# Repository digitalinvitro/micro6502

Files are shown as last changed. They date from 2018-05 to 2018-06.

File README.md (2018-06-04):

# micro6502

6502 cpu based micro module (for mcu applications)

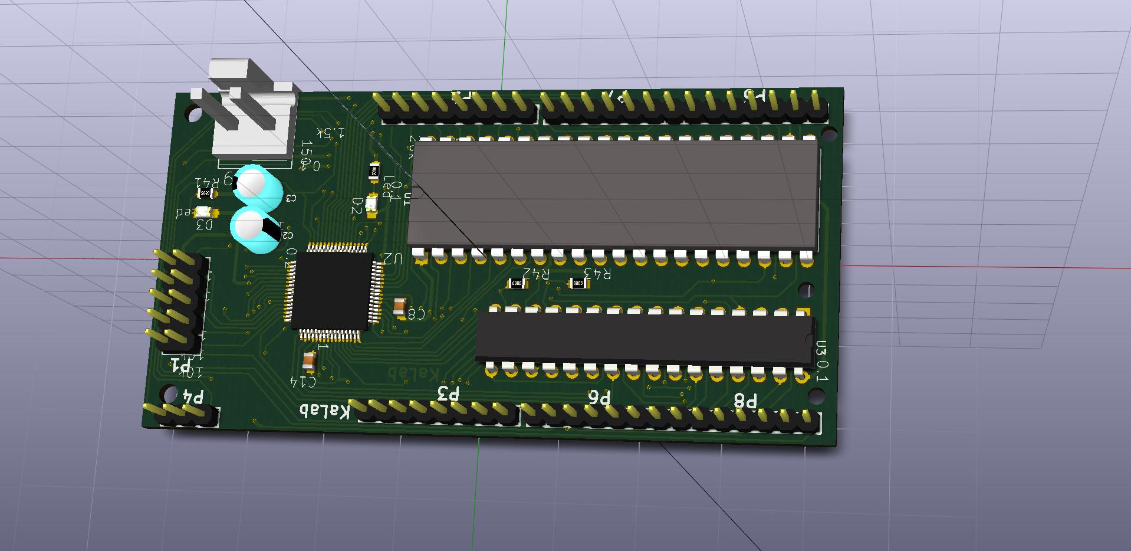
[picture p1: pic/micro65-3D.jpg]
3D view


Hardware

- CPU mos6502 - 1MHz
- 16 IO port in zero-page low address (0x0000...0x000F)
- 64K SRAM
- UART RX/TX
- load 256-byte MONITOR to SRAM from UART (terminal) on power on
- 16-bit address bus, 8-bit data bus, control bus and 16 IO pin to pinheaders connected
- option spi/i2c/SN74HC595/dendy joystik(HEF4021B) interfaces HDL programmed in CPLD

Программное обеспечение:
* АССЕМБЛЕР - naken asm http://www.mikekohn.net/micro/naken_asm.php
* МОНИТОР   - программное обеспечение для начальной загрузки модуля по включению питания. Загружается с адреса 0xFF00, после загрузки 256 байт кода, на процессор подается питание с последюущим сбросом по лининии reset. 
* ОТЛАДЧИК  - программное обеспечение для отладки загружаемого кода, интерфейс строчный. Загружается с адреса 0x1000.
 
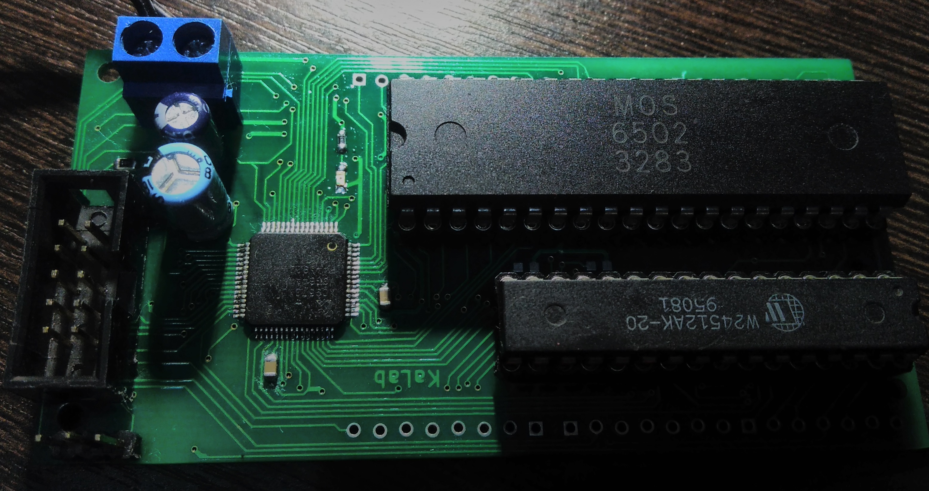
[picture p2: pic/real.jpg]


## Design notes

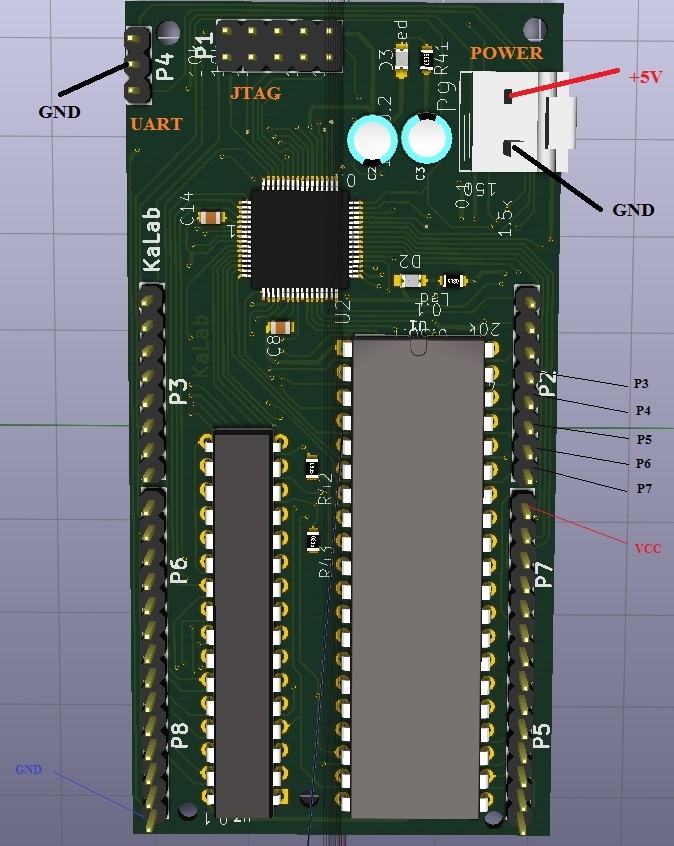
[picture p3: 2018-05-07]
pic/board.jpg

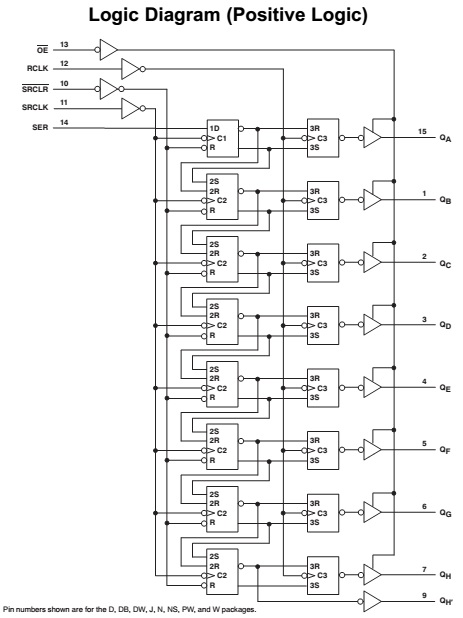
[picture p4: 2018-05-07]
pic/SN74HC595-ls.jpg

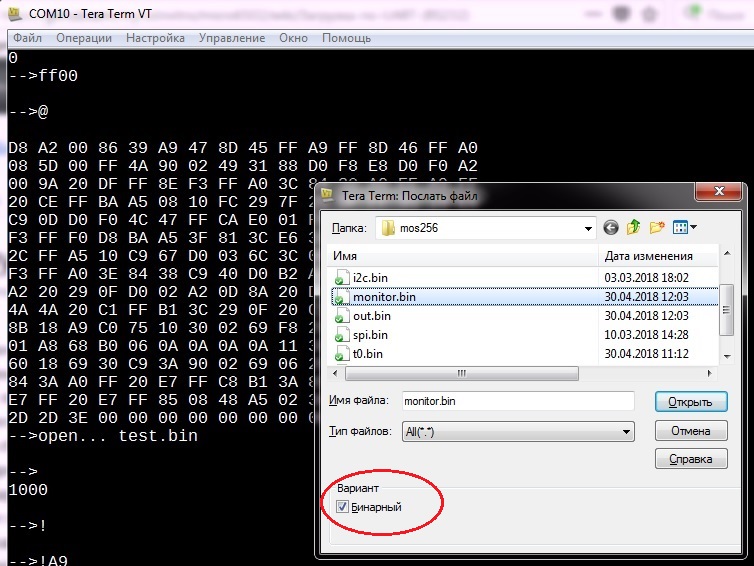
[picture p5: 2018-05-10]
pic/boot.jpg

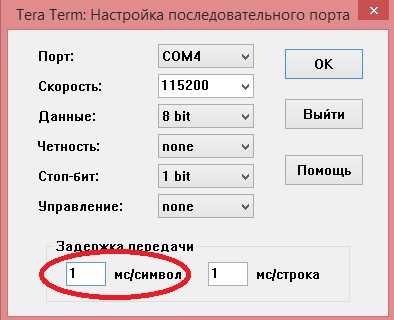
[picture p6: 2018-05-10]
pic/com-set.jpg

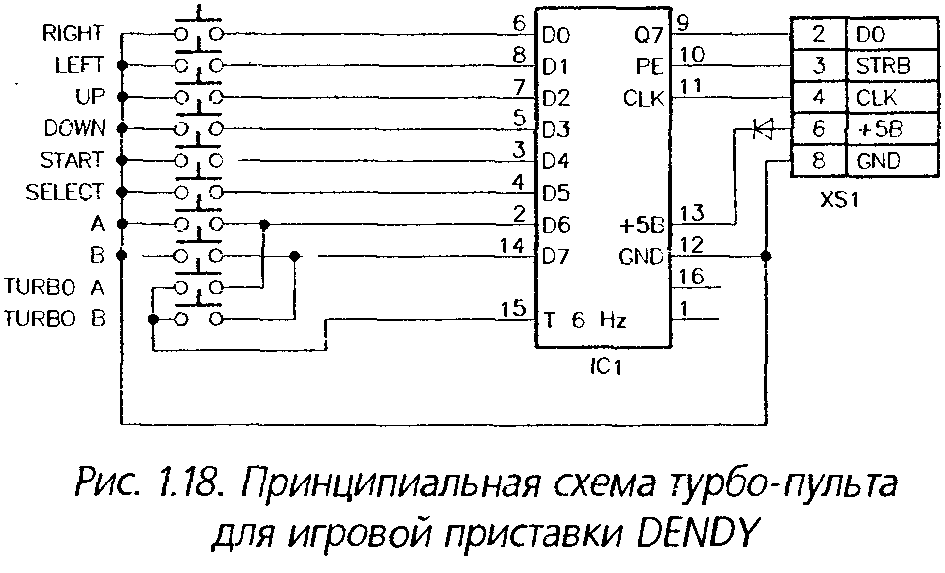
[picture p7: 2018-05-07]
pic/shema_2561f6.jpg

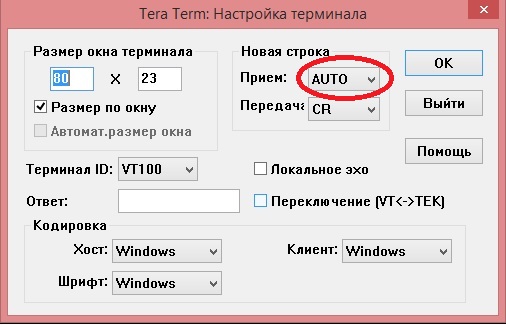
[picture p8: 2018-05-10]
pic/term-set.jpg

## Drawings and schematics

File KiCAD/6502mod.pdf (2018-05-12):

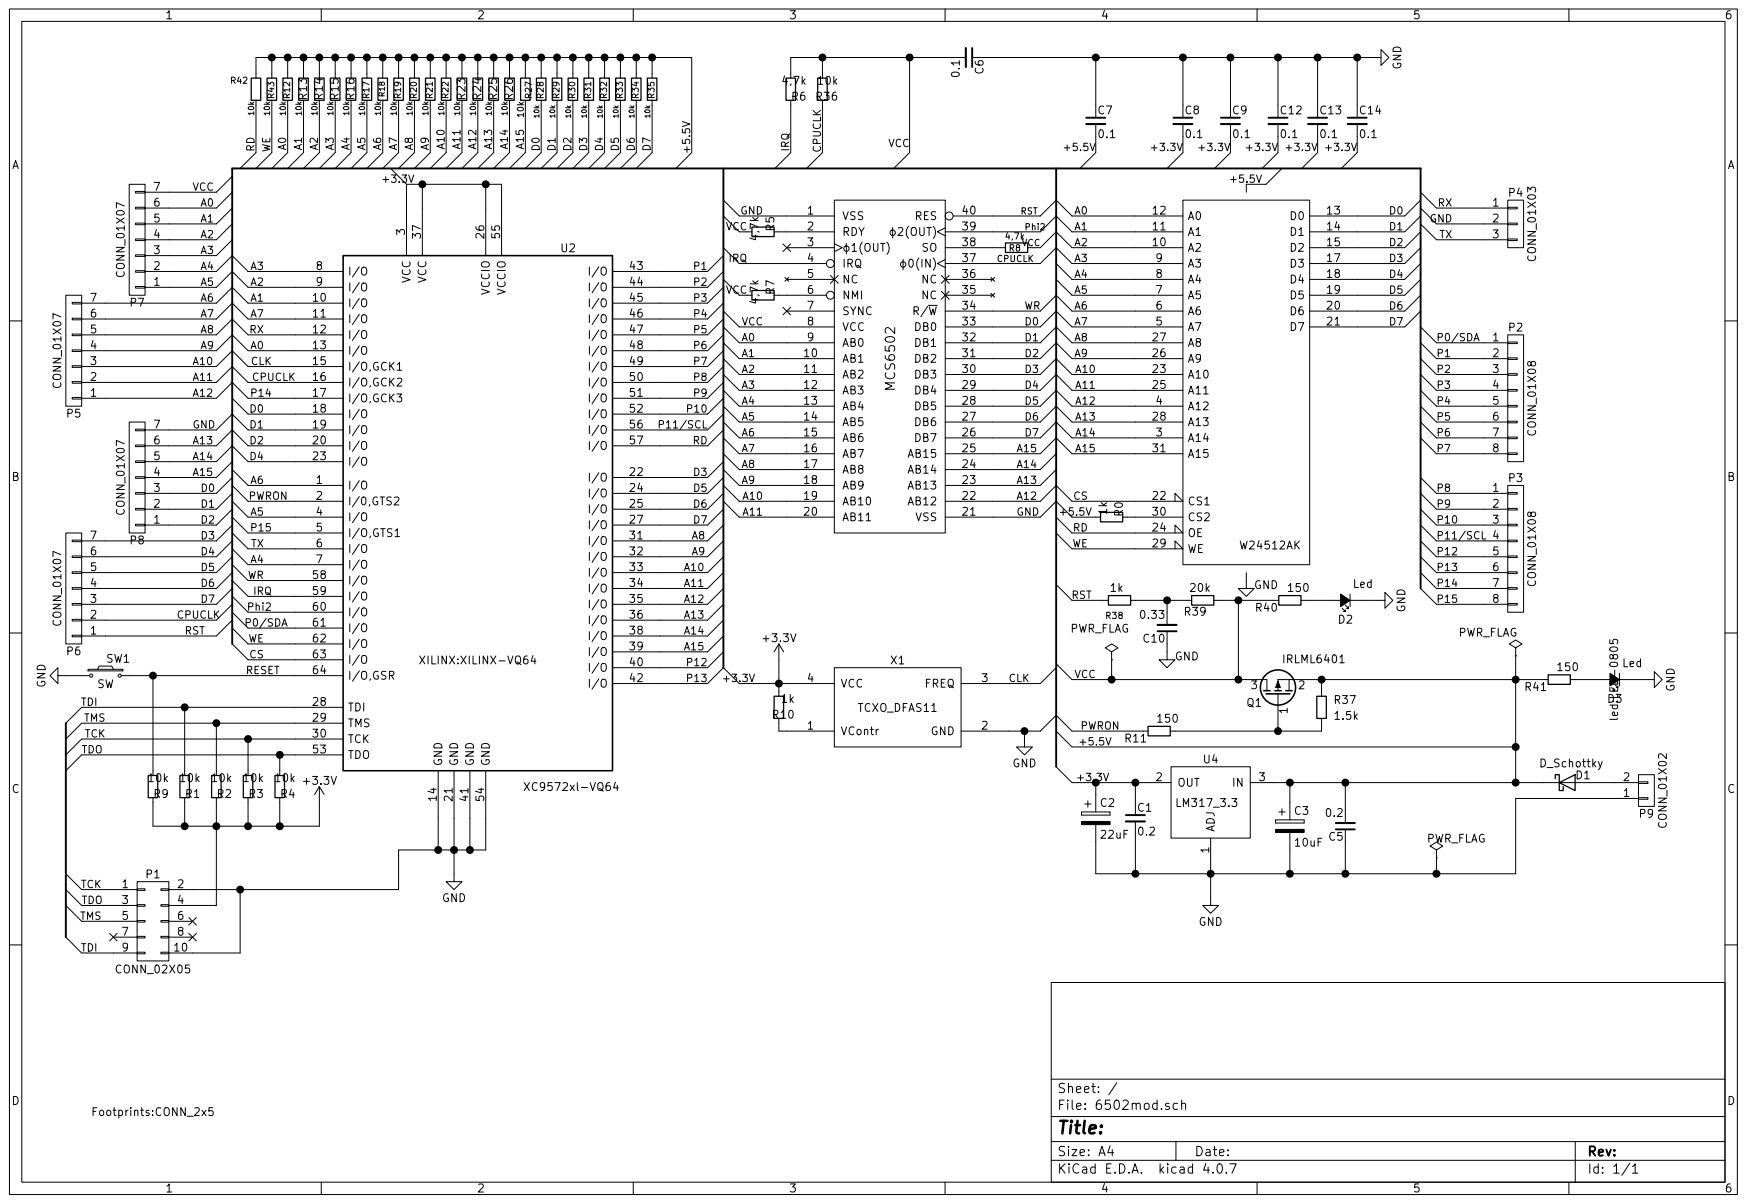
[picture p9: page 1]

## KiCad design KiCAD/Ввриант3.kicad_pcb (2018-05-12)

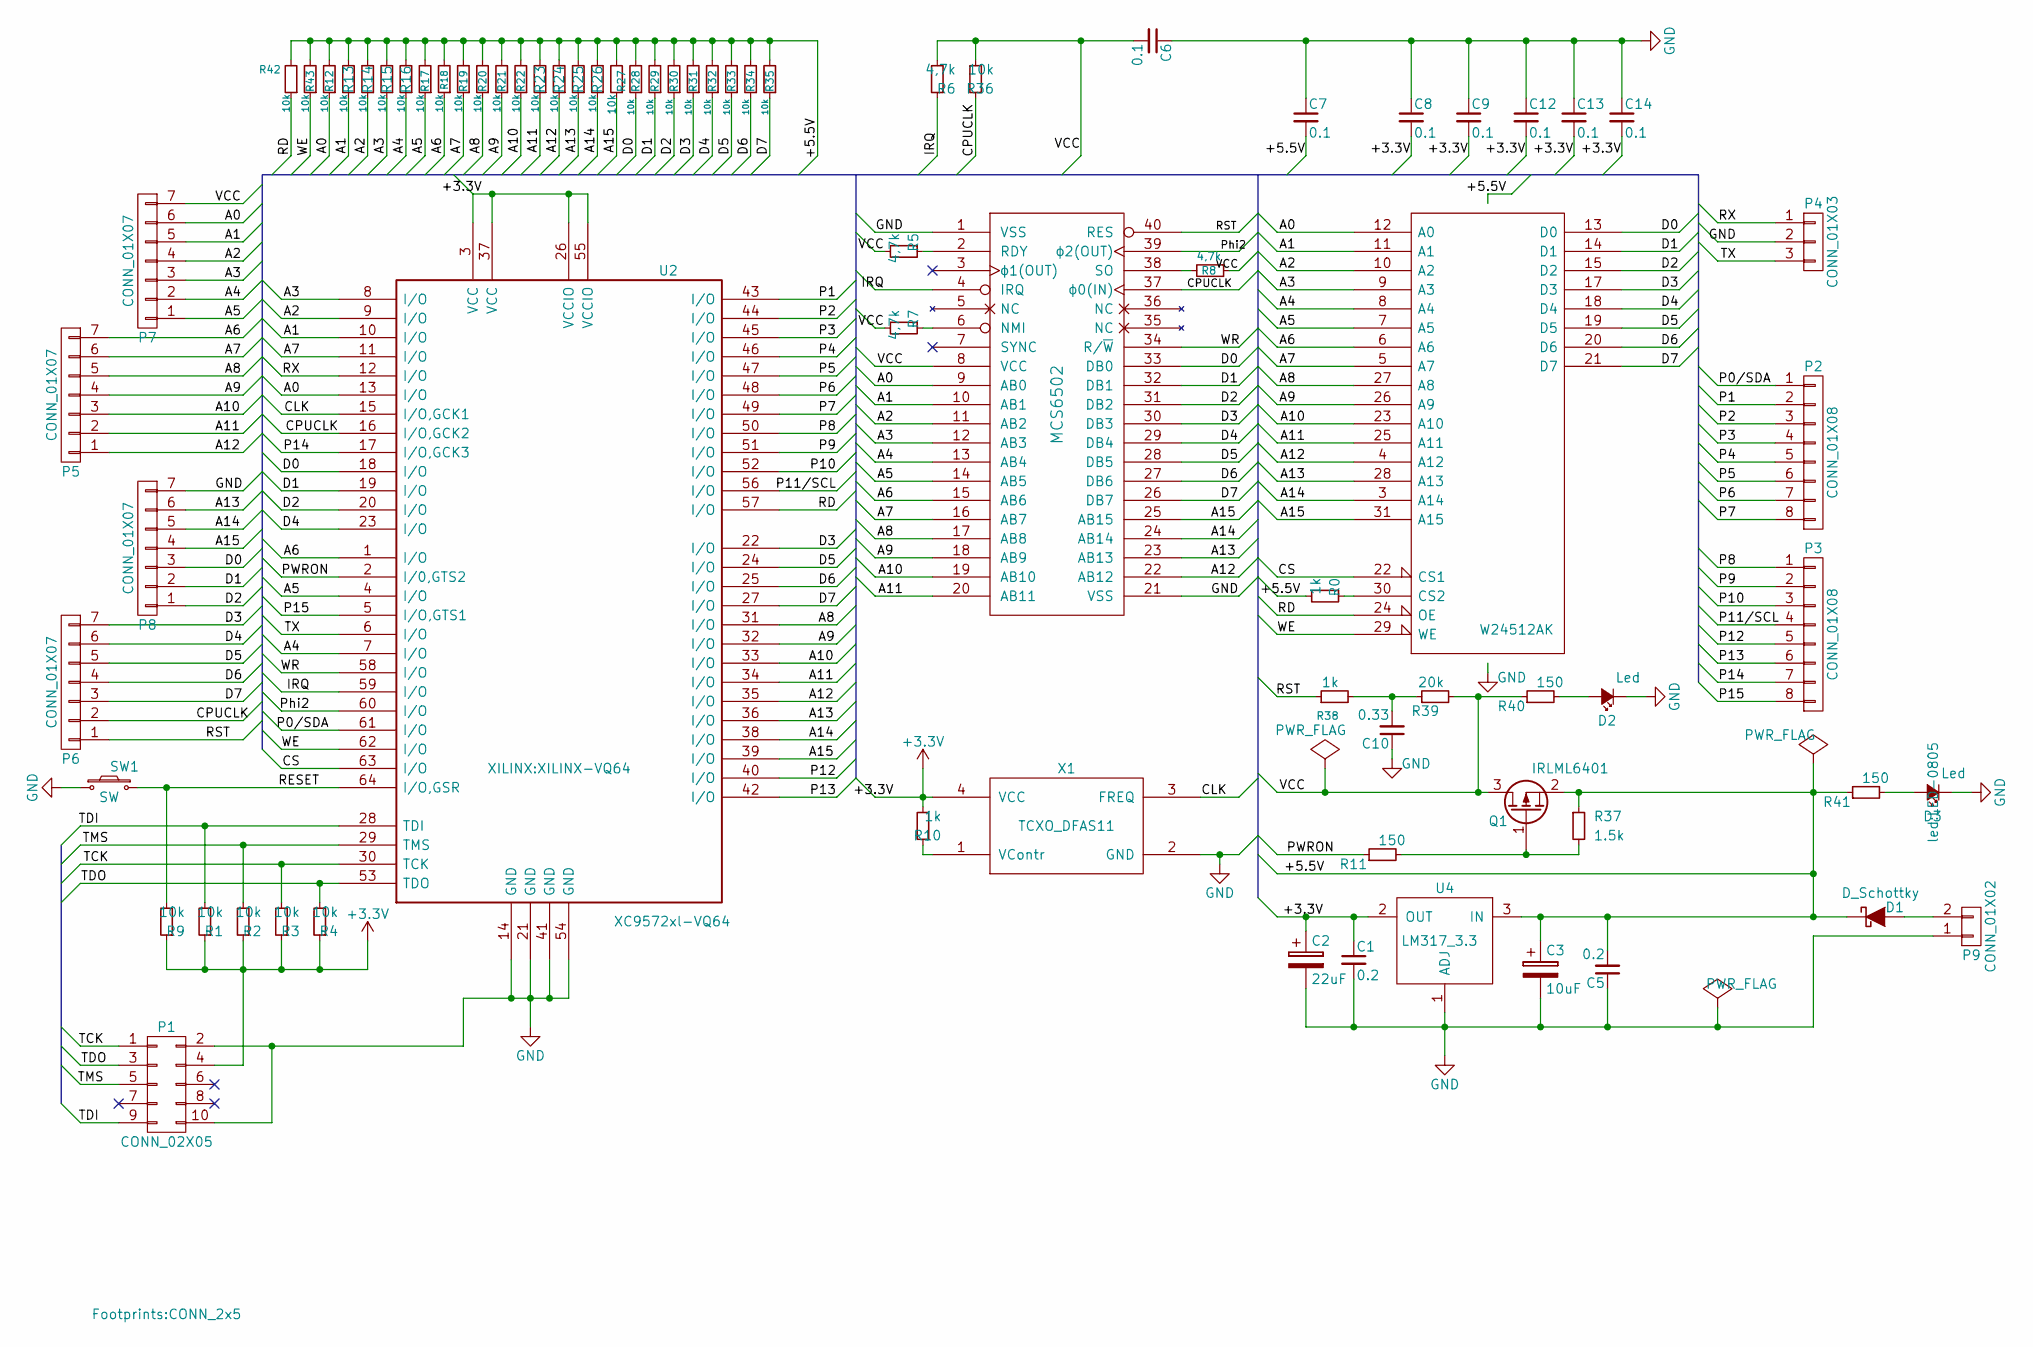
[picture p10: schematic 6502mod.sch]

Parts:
C1: 0.2; m-pad-2.1-0603
C2: 22uF; C1V5
C3: 10uF; C1V5
C5: 0.2; m-pad-2.1-0603P
C6, C7, C8, C9, C12, C13, C14: 0.1; m-pad-2.1-0603P
C10: 0.33; m-pad-2.1-0603
D1: D_Schottky; m-pad-2.1-1206P
D2, D3: Led; LED-0805
P1: CONN_02X05; CONN_2x5
P2, P3: CONN_01X08; CONN_1x8
P4: CONN_01X03; CONN_1x3
P5, P6, P7, P8: CONN_01X07; CONN_1x7
P9: CONN_01X02; connect-CLAMP-02
Q1: IRLML6401; transistor-SOT23
R0, R10, R38: 1k; m-pad-2.1-0603
R1, R2, R3, R4, R9, R12, R13, R14, R15, R16, R17, R18, R19, R20, R21, R22, R23, R24, R25, R26, R27, R28, R29, R30, R31, R32, R33, R34, R35, R36, R42, R43: 10k; m-pad-2.1-0603
R5, R6, R7, R8: 4,7k; m-pad-2.1-0603
R11, R40, R41: 150; m-pad-2.1-0603
R37: 1.5k; m-pad-2.1-0603
R39: 20k; m-pad-2.1-0603
SW1: SW; SW_SPST_EVQP0
U1: MCS6502; DIP-40_W15.24mm
U2: XC9572xl-VQ64; XILINX-VQ64
U3: W24512AK; DIP-32_W7.62mm
U4: LM317_3.3; m-pad-2.1-SOT223
X1: TCXO_DFAS11; m-pad-2.1-ASVK

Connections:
+3V3: C1.1, C2.1, C8.2, C9.2, C12.2, C13.2, C14.2, P1.4, R1.1, R2.1, R3.1, R4.1, R9.1, R10.2, U2.3 (VCC), U2.26 (VCCIO), U2.37 (VCC), U2.55 (VCCIO), U4.2 (OUT), X1.4 (VCC)
/+5.5V: C3.1, C5.2, C7.2, D1.1 (K), Q1.2 (S), R0.2, R12.2, R13.2, R14.2, R15.2, R16.2, R17.2, R18.2, R19.2, R20.2, R21.2, R22.2, R23.2, R24.2, R25.2, R26.2, R27.2, R28.2, R29.2, R30.2, R31.2, R32.2, R33.2, R34.2, R35.2, R37.1, R41.1, R42.2, R43.2, U3.32 (VCC), U4.3 (IN)
/A0: P7.6, R12.1, U1.9 (AB0), U2.13 (I/O), U3.12 (A0)
/A1: P7.5, R13.1, U1.10 (AB1), U2.10 (I/O), U3.11 (A1)
/A2: P7.4, R14.1, U1.11 (AB2), U2.9 (I/O), U3.10 (A2)
/A3: P7.3, R15.1, U1.12 (AB3), U2.8 (I/O), U3.9 (A3)
/A4: P7.2, R16.1, U1.13 (AB4), U2.7 (I/O), U3.8 (A4)
/A5: P7.1, R17.1, U1.14 (AB5), U2.4 (I/O), U3.7 (A5)
/A6: P5.7, R18.1, U1.15 (AB6), U2.1 (I/O), U3.6 (A6)
/A7: P5.6, R19.1, U1.16 (AB7), U2.11 (I/O), U3.5 (A7)
/A8: P5.5, R20.1, U1.17 (AB8), U2.31 (I/O), U3.27 (A8)
/A9: P5.4, R21.1, U1.18 (AB9), U2.32 (I/O), U3.26 (A9)
/A10: P5.3, R22.1, U1.19 (AB10), U2.33 (I/O), U3.23 (A10)
/A11: P5.2, R23.1, U1.20 (AB11), U2.34 (I/O), U3.25 (A11)
/A12: P5.1, R24.1, U1.22 (AB12), U2.35 (I/O), U3.4 (A12)
/A13: P8.6, R25.1, U1.23 (AB13), U2.36 (I/O), U3.28 (A13)
/A14: P8.5, R26.1, U1.24 (AB14), U2.38 (I/O), U3.3 (A14)
/A15: P8.4, R27.1, U1.25 (AB15), U2.39 (I/O), U3.31 (A15)
/CLK: U2.15 (I/O,GCK1), X1.3 (FREQ)
/CPUCLK: P6.2, R36.1, U1.37 (ɸ0(IN)), U2.16 (I/O,GCK2)
/CS: U2.63 (I/O), U3.22 (CS1)
/D0: P8.3, R28.1, U1.33 (DB0), U2.18 (I/O), U3.13 (D0)
/D1: P8.2, R29.1, U1.32 (DB1), U2.19 (I/O), U3.14 (D1)
/D2: P8.1, R30.1, U1.31 (DB2), U2.20 (I/O), U3.15 (D2)
/D3: P6.7, R31.1, U1.30 (DB3), U2.22 (I/O), U3.17 (D3)
/D4: P6.6, R32.1, U1.29 (DB4), U2.23 (I/O), U3.18 (D4)
/D5: P6.5, R33.1, U1.28 (DB5), U2.24 (I/O), U3.19 (D5)
/D6: P6.4, R34.1, U1.27 (DB6), U2.25 (I/O), U3.20 (D6)
/D7: P6.3, R35.1, U1.26 (DB7), U2.27 (I/O), U3.21 (D7)
/IRQ: R6.1, U1.4 (IRQ), U2.59 (I/O)
/P0/SDA: P2.1, U2.61 (I/O)
/P1: P2.2, U2.43 (I/O)
/P2: P2.3, U2.44 (I/O)
/P3: P2.4, U2.45 (I/O)
/P4: P2.5, U2.46 (I/O)
/P5: P2.6, U2.47 (I/O)
/P6: P2.7, U2.48 (I/O)
/P7: P2.8, U2.49 (I/O)
/P8: P3.1, U2.50 (I/O)
/P9: P3.2, U2.51 (I/O)
/P10: P3.3, U2.52 (I/O)
/P11/SCL: P3.4, U2.56 (I/O)
/P12: P3.5, U2.40 (I/O)
/P13: P3.6, U2.42 (I/O)
/P14: P3.7, U2.17 (I/O,GCK3)
/P15: P3.8, U2.5 (I/O,GTS1)
/PWRON: R11.1, U2.2 (I/0,GTS2)
/Phi2: U1.39 (ɸ2(OUT)), U2.60 (I/O)
/RD: R42.1, U2.57 (I/O), U3.24 (OE)
/RESET: R9.2, SW1.2, U2.64 (I/O,GSR)
/RST: P6.1, R38.1, U1.40 (RES)
/RX: P4.1, U2.12 (I/O)
/TCK: P1.1, R3.2, U2.30 (TCK)
/TDI: P1.9, R1.2, U2.28 (TDI)
/TDO: P1.3, R4.2, U2.53 (TDO)
/TMS: P1.5, R2.2, U2.29 (TMS)
/TX: P4.3, U2.6 (I/O)
/VCC: C6.2, P7.7, Q1.3 (D), R5.2, R6.2, R7.2, R8.1, R36.2, R39.2, R40.1, U1.8 (VCC)
/WE: R43.1, U2.62 (I/O), U3.29 (WE)
/WR: U1.34 (R/~W), U2.58 (I/O)
GND: C1.2, C2.2, C3.2, C5.1, C6.1, C7.1, C8.1, C9.1, C10.1, C12.1, C13.1, C14.1, D2.1, D3.1, P1.2, P1.10, P4.2, P8.7, P9.1, SW1.1, U1.1 (VSS), U1.21 (VSS), U2.14 (GND), U2.21 (GND), U2.41 (GND), U2.54 (GND), U3.16 (GND), U4.1 (ADJ), X1.2 (GND)
unnamed: C10.2, R38.2, R39.1
unnamed: D1.2 (A), P9.2
unnamed: D2.2, R40.2
unnamed: D3.2, R41.2
unnamed: Q1.1 (G), R11.2, R37.2
unnamed: R0.1, U3.30 (CS2)
unnamed: R5.1, U1.2 (RDY)
unnamed: R7.1, U1.6 (NMI)
unnamed: R8.2, U1.38 (SO)
unnamed: R10.1, X1.1 (VContr)

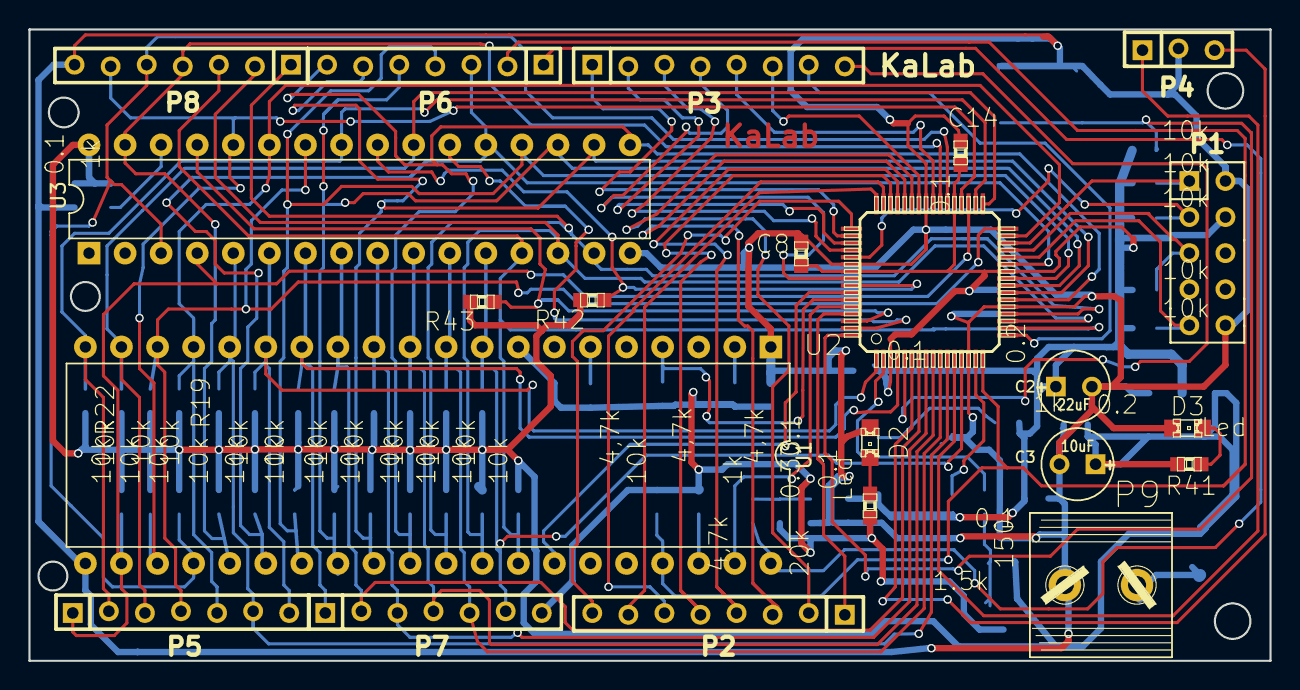
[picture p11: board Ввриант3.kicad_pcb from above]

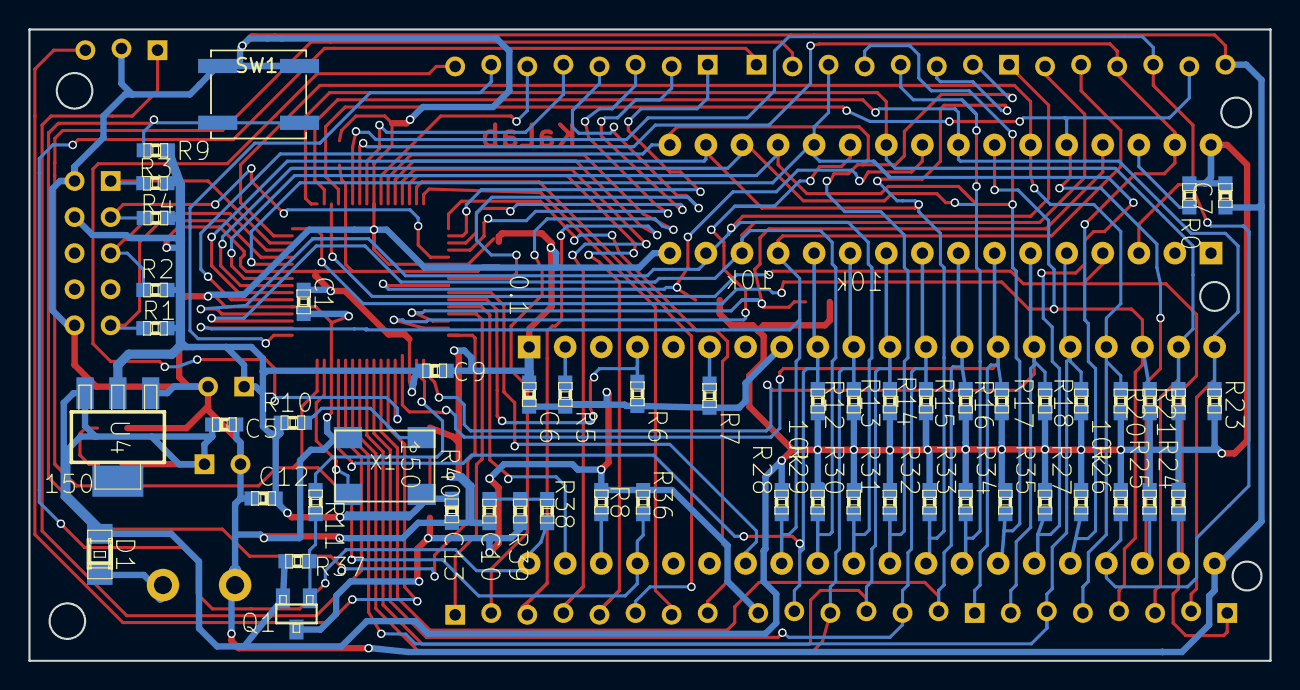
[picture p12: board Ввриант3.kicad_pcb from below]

Board: 2 copper layers, 87.4 x 44.5 mm, 75 parts (53 on the bottom side), 71 nets.

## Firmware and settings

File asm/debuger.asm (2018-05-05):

        .6502
        .include "core.inc"
        .org    0x1000
main:
        write(hello)
        lda     #(break  & 0x00FF)
        sta     0xFFFE
        lda     #((break>>8) & 0x00FF)
        sta     0xFFFF
        lda     #(parser & 0x00FF)
        sta     HOOK+0
        lda     #((parser>>8) & 0x00FF)
        sta     HOOK+1
        jmp     MONITOR
;====================================================================================
;  Disassm Func
;====================================================================================
disasm_table:
        DB      C0&0xFF, C1&0xFF, C2&0xFF, C3&0xFF, C4&0xFF, C5&0xFF, C6&0xFF, C7&0xFF, C8&0xFF, C9&0xFF, CA&0xFF, CB&0xFF, CC&0xFF, CD&0xFF, CE&0xFF, CF&0xFF
C0:;******************************************************************************************************
; 0 - opcode column 
;******************************************************************************************************
        beq     _imm_                   ;#2
        cmp     #0x20                   ;#2
        beq     _abs_                   ;#2
        bvs     _imm_                   ;#2
        bne     _impl                   ;#2
C1:;******************************************************************************************************
; 1 - opcode column                          comand group indirect access to memory (adr, x); (adr), y
;******************************************************************************************************
        bvc     _ind_y
        ldx     #Lo(indx)
        rts
C4:;******************************************************************************************************
; 4 - opcode column                          
;******************************************************************************************************
        bvs     _zp_x
C5:;******************************************************************************************************
; 5 - opcode column                          
;******************************************************************************************************
        bvs     _zp_x
_zp_:
        ldx     #Lo(zp)
        rts
C6:;******************************************************************************************************
; 6 - opcode column                          
;******************************************************************************************************
        bvc     _zp_
        cmp     #0x90                   ;#2
        beq     _zp_y                   ;#2
        cmp     #0xB0                   ;#2
        bne     _zp_x                   ;#2  << 10 byte
C8:;******************************************************************************************************
CA:; 8, A - opcode column                          
;******************************************************************************************************
_impl:
        ldx     #Lo(unk+7)              ;#2 no text after mnenmonics
        rts
C9:;******************************************************************************************************
; 9 - opcode column                          
;******************************************************************************************************
        bvs     _abs_y
        bvc     _imm_
CC:;******************************************************************************************************
; C - opcode column                          
;******************************************************************************************************
        cmp     #0x60                   ;#2
        bne     CD                      ;#2
_imm_:
        ldx     #Lo(imm)                ;#2 no text after mnenmonics
        rts
CE:;******************************************************************************************************
; E - opcode column                          
;******************************************************************************************************
        cmp     #0xB0                   ;#2
        beq     _abs_y                  ;#2
CD:;******************** D - opcode 
        bvs     _abs_x
_abs_:
        ldx     #Lo(abs)                ;#2 no text after mnenmonics
        rts

_abs_x:
        ldx     #Lo(absx)               ;#2 no text after mnenmonics
        rts
_abs_y:
        ldx     #Lo(absy)               ;#2 no text after mnenmonics
        rts
_zp_y:
        ldx     #Lo(zpy)
        rts
_zp_x:
        ldx     #Lo(zpx)
        rts
_ind_y:
        ldx     #Lo(indy)
        rts
;----NOT ASM MNEMO
C2:
C3:
C7:
CB:
CF:
        lda     #Lo(unk)
        rts
;======================================================================
; operand from code[(EXEC)+y] convert hex, copy to shbllist|x
;======================================================================
oper2hex:
	inc	YEXEC                   ;#2
        lda     (EXEC), y		;#2
        jsr     THi2Hex                 ;#3
        sta     shblst & 0xFF00, x      ;#3
        inx                             ;#1
        lda     (EXEC), y               ;#2
        jsr     TLo2Hex                 ;#3
        sta     shblst & 0xFF00, x      ;#3
	inx                             ;#1
	rts
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

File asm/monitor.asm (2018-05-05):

; read 1  - port busy UART transmitter TX
; read 0  - port busy UART resciver RX
; write 1 - port DATA UART transmitter TX-data
        .6502
        .include "boot.inc"
        .org    0xff00

.macro write(string)
        ldy     #(string & 0x00FF)      ; 2
        lda     #(string >> 8)          ; 2
        jsr     output                  ; 3
.endm
.macro ParserTo(variable)
        ldy     #(variable & 0x00FF)    ; #2  Y=low byte for ADDR
        sty     pVAR+0                  ; #2  change only low byte of word pVAR  
.endm
reset:
        cld
        ldx     #0                      ; 2
        stx     pVAR+1                  ; 2  high byte of word pVAR constant = 00
;----------------------------------------------------------------------------------
; reset menu hook
;----------------------------------------------------------------------------------
        lda     #(boot_jmp & 0x00FF)    ;#2
        sta     hook_cmd+1              ;#3
        lda     #0xFF                   ;#2
        sta     hook_cmd+2              ;#3
;----------------------------------------------------------------------------------
; CRC 8 calc for RAM 0xFF00..0xFFFF (#18)
;----------------------------------------------------------------------------------
crc:
;        lda     #0xFF                   ; #2
for_x:
        ldy     #8                      ; #2
        eor     0xFF00, x               ; #3     crc^pcBlock
for_y:
        lsr                             ; #1     crc <<= 1
        bcc     no_change               ; #2
        eor     #0x31                   ; #2     crc ^= 0x31
no_change:
        dey                             ; #1
        bne     for_y                   ; #2
        inx                             ; #1
        bne     for_x                   ; #2
;----------------------------------------------------------------------------------
; ERORR hook - exception from input strem erro simbol
;----------------------------------------------------------------------------------
error_hook:                             ; ERROR HOOK
        ldx     #0
        txs
        jsr     putc                    ; print CRC or ERROR symbol
; pVAR point to var
        stx     text+5                  ; #3  menu -> root (text[7]=0)
        ParserTo(ADDR)                  ; #4  parser pointer -> ADDR
main:
        write(text)                     ; #3   a, y - crashed
;==================================================================================
;  UART -> buffer, X=0
;==================================================================================
        tsx                             ; SP=0, 0 -> x
next_rx:
;        jsr     busy
ready_rx:
        lda     UART
        bpl     ready_rx
        and     #0x7F                   
        jsr     putc                    ;#3
        sta     <buffer, x
        inx
        cmp     #0x0D
        bne     next_rx
hook_cmd:
        jmp     boot_jmp                  ; call back 
boot_jmp:
        dex
        cpx     #1
        beq     chk_command               ; buffer len=1, then input one char - command
        jsr     pars_num                  ; #3
;==================================================================================
;  string parsed in to BYTE-numeric or WORD-numeric
;  check MODE, select procedure
;==================================================================================
        lda     text+5                    ; #3 0D,0A,-,-,>,MODE
        beq     main                      ; #2 if MODE == 0 then main else wr_byte
;==================================================================================
;  MODE ---- WRITE BYTE
;    BYTE-numeric write to ADDRESS, ADDRESS increment
;==================================================================================
wr_byte:
        tsx                               ;#1 x=0
        lda     value+1                   ;#2 load input and parsing byte
        sta     (ADDR, x)                 ;#2 store input byte to pointer *(var+x), x = 0
;----- pointer++  -----------------------------------------------------------------
        inc     ADDR+0
        bne     main                      ; (ADDR+0) != 0, then (ADDR+1) d'nt incremented
        inc     ADDR+1
;----------------------------------------------------------------------------------
        jmp     main
;==================================================================================
;  switch on COMMAND
;==================================================================================
chk_command:
        lda     <buffer                   ; #2 first char - command
        cmp     #'g'                      ; #2
        bne     is_store                  ; #2 command not recognition - repeat input
;==================================================================================
; case: COMMAND - 'g'  GOTO ADDR
;==================================================================================
        jmp     (ADDR)                    ; command 'g' - go ADDR
is_store:
        cmp     #'!'                      ; #2
        bne     is_dump                   ; #2
;==================================================================================
; case: COMMAND - '!'  STORE input byte
;==================================================================================
        sta     text+5                    ; #3  A='!' -> change menu mode to WRITE BYTE
        ParserTo(value)                   ; #4  parser pointer -> value
; change pVAR pointer to byte VALUE
;        ldy     #(value & 0x00FF)         ; #2  Y=low addr for value
;        sty     pVAR+0                    ; #2  change only low byte of word pVAR
is_dump:
        cmp     #'@'                      ; #2
        bne     main                      ; #2
;==================================================================================
;  case: COMMAND - '@' DUMP (dump 256 byte from [pVar])
;==================================================================================
        ldy     text+5                    ; #2    load mode
        bne     error_hook                ; #2    mode != 0, then stoped MODE WRITE BYTE
next_byte:                                  
        tya                               ; #1
        ldx     #' '                      ; #2
        and     #0x0F                     ; #2
        bne     no_wrap                   ; #2
        ldx     #CR                       ; #2  
no_wrap:
        txa                               ; #1
        jsr     putc                      ; #3

        lda     (ADDR), y                 ; #2
; HI tetrade output
        lsr                               ; #1
        lsr                               ; #1
        lsr                               ; #1
        lsr                               ; #1
        jsr     tetr2hex                  ; #3
; LO tetrade output
        lda     (ADDR), y                 ; #2
        and     #0x0F                     ; #2
        jsr     tetr2hex                  ; #3
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
